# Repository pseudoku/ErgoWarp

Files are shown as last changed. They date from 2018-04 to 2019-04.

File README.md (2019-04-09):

# ErgoWarp
Design Log and Code Repo for ''''Customizable'''' Split Keyboard

# **Still under construction, expect a lot of idiotic word salad and grammatical errors**
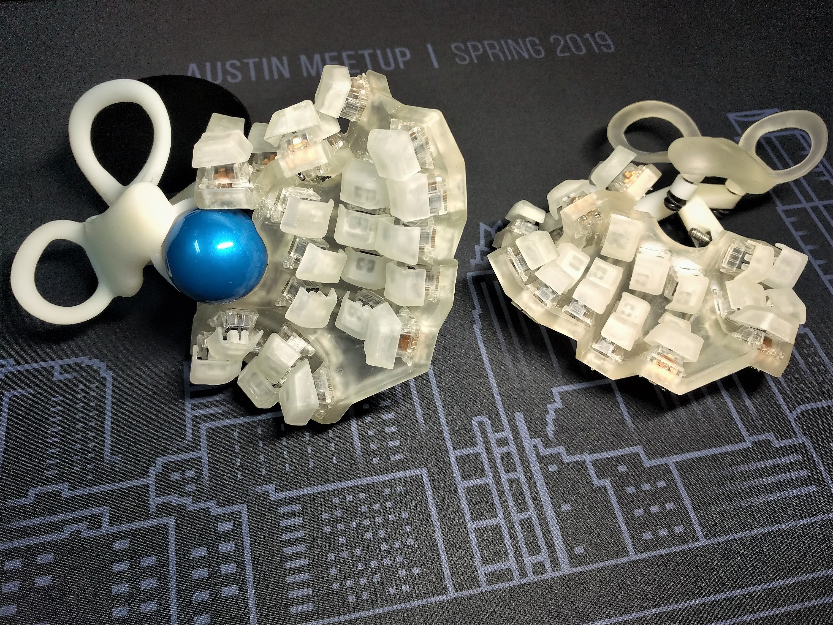
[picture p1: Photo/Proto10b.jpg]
Prototype Rev 10


## Index
 * Introduction
 * Design Goals
 * Design Justifications
  * Row Placement
  * Column Placement
  * Compact Switches
  * Thumb Cluster Design
  * Palm Rest Design
  * Tracking Device Design
 * Observation
 * Alternate Layout

## Introduction

Thanks to this ever-growing and enthusiastic community, there are several options for [split scooped keyboard designs](https://github.com/BenRoe/awesome-mechanical-keyboard) and if you are willing to put some effort into printing and building a pair, you can have your very own as well. However, once I began to play around with them, they raised more questions than what they seemed fix: typing experience of thumb cluster and pinkie columns improved, but still felt awkward at times, necessity to still move my wrist in order to access inner index columns, why not account the key orientations and contour radius to actual fingers motion? etc. etc. I could no longer justify why I need to suffer physically by design concepts of kind and knowledgeable, yet intangible netizen smug with their take on this modern torturing device. I want in on smugness quotas, too. So began my financial woe and mental suffering... And here you are, dredging up this repo page somehow and before your waning attention span exhaust, I will attempt to describe my concepts and experiences of this process in details you have never asked for.

Glory to Datahand and Tron, our ergo forefathers.

## Design Goals:
* Customizable parametric key placement
* Minimize finger movement
* Dense and comfortable thumb cluster
* Built-in ~~adjustable~~ palm rest
* Adjustable tenting
* Tracking device

## Design Justifications

### Row Placement
**Mapping finger flexion to a placement function:**
 To achieve a minimum finger movement, more aggressive row wise contour is desirable. Let us define two arcs of a finger tip during a flexion: inner (distal and intermediate flexion) and outer(distal, intermediate, proximal flexion) with palm side of metacarpal phalangeal joint as the origin. These arcs are mapped to a parametric functions defining the radius of an arc at a given angle from origin with 0° as neutral full extension and 90° as full flexion. They simulate trigger motion and grab motion respectively and it is assumed that optimal row placements of keys reside somewhere between two such functions.

 Please put Finger Path image here

 Using a CAD program I devised following ad hoc rules that will accommodate switches in the arcs.

* Define R0 as a natural trigger, orientated tangential to the inner arc at θ= ~90° to simulate full flexion. Switch origin is offset to the top of mx switch housing.
* Define R2 as a natural tap, orientated normal to the outer arc at θ= ~60°. Switch origin is bottom of the mx switch housing.
* Define R1 as a neutral position that reside between above mentioned positions based on the following rules. Switch origin is bottom of the mx switch housing.
  * Define secondary origin, an intermediate joint of a finger at natural full extension θ= 0°
  * An angle bisected by vectors pointing to the secondary origin R0 and R2 position.
  * Intersection of bisected vector and the outer path and key orientated normal to the path.
* Define R3 as a mirrored of R1 vector across R2. Switch origin is bottom of the mx switch housing.

#### Additional parameters

**path radius offset:** for shorter fingers (ring and pinkie for me), switches origin must be offset to accommodate the switch and keycaps to avoid collision.  

**roll angle:** When I fold my fingers, fingertip does not stay parallel nor in-plane with respect to vector spanned by proximal phalanx and metacarpal. This deviation becomes noticeable with high contour column and column origin transformation does not correct it.(such as adding yaw: see below section). Therefore, roll transformation was added to reorient switches out of columnar plane to bring key orientation closer to natural path of finger tips.

### Column Design
Each origins of columns defined above can be transformed to fit the natural spread and orientation of fingers. For better (ergonomically) or worse (design complexity), We can loosen the orthogonality restriction between columns and gain the freedom to yaw and roll the columns to conform to the arch of palm. With the traditional mx switch and keycap, the out of plane features collide with adjacent columns when optimized for correct placement. Without desperate measures, as we will discuss later, the compromised placement with a high contour leads to a typing experience that was subpar at best, given my finger length and spread. Major issue was that the outer most keys such as outer index and pinkie top rows required wrist motion and exaggerated extensions to hit the keys. This may not be the case for those with longer fingers and requires inputs from those who is willing to try this design.

Notes on some of the observations made during the design iteration on each columns without applying compact switches.
* Column 0: (Ternary Index) though feasible, difficult to press and infrequently used key set recommended (see Prototype 1) R0 is somewhat accessible, if you must.
* Column 1: (Secondary Index) Rolled by 20°, at this angle R0 caps (DSA) corner must be shaved.
* Column 2: (Primary Index)  not rolled, though ideally 15° is desirable, but it would collide with C3. There is also natural yaw of ~12°, but in order to accommodate C0 & C1 it is ignored.
* Column 3: (Middle) 9° roll. ideally more is desirable.   
* Column 4: (Ring) 12° switch roll. ~10° yaw is desirable.  
* Column 5: (Pinky) neutral position has great enough yaw ~42° to split the column from the rest, as observed in top view.
 column without aggressive yaw was tested, but the result required continual effort to keep finger on columns.
* Column 6: (Secondary Pinky) R0 and R1 is good candidate. It's an attractive option if you wish to support such tradition rather than using the thumb cluster.  

### Compact Switches
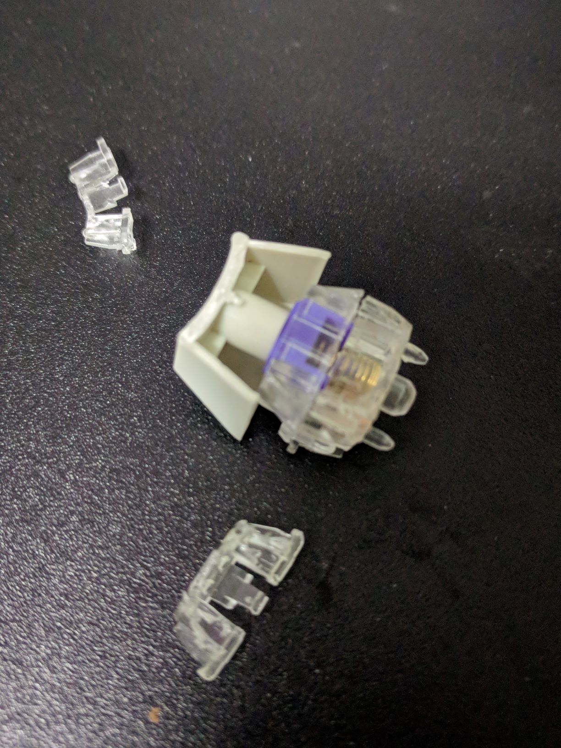
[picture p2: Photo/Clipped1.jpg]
Poor man's compact switches

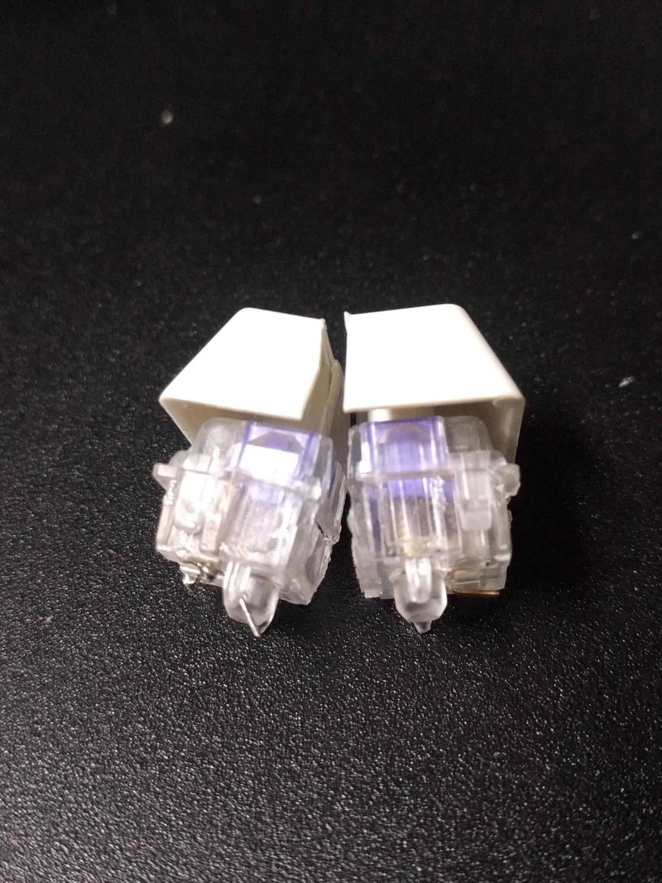
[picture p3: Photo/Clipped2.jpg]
That's a lot of damage

My initial intention of this project was to keep the design accessible by limiting to commercially available switches and keycaps, I did not wish to invest time redesigning key profiles; however, what was available no longer sufficed to the requirement: narrower design something along the line of [alps SKCM compact](https://www.desthority.com) was needed. These are *not readily available* in large quantities and keycaps more so. As a desperation, I resorted to lopping off the LED compartment of MX switches as well as few keycaps to test the feasibility of such. The result was not pleasing to say the least, but it allowed optimization. Not entirely enthralled, but few test prints proved that the pro out weighed the cons:

#### cons:
* produced large wobble that hinders off axis press without gluing casing together
* switch will no longer seat flush to the plate and will tilt without additional support (PCB or glue)
* normal clipped keycap profile are no longer viable and custom profile will be required to improve typing comfort.

#### pros:
* by clipping switch column wise, column separation can be reduced
  * especially useful for outer columns, which reduce wrist motions and extension required.
* allows more aggressive row contour when necessary.
  * by clipping switch row wise, extension need to actuate adjacent upper row can be reduced: pinkie home row (C5R1)
  * by clipping switch row wise, reduce off axis press for num: ring and middle num row (C3&4R3s)
* allows more aggressive column rolling and yaw
  * more natural ring and pinkie column orientation
* allows thumb cluster optimization (discussed next section)

Custom key caps brought some benefits as well:
* inclined tilt for upper row improves actuation motion    
* convex curvature for R0 to reduce discomfort  

Notes on column with compact switches.
* **Column 0: (Ternary Index)
* Column 1: (Secondary Index)
* Column 2: (Primary Index)  not rolled, though ideally 15° is desirable, but it would collide with C3. There is also natural yaw of ~12°, but in order to accommodate C0 & C1 it is ignored.
* Column 3: (Middle) 9° roll. ideally more is desirable.   
* Column 4: (Ring) 12° switch roll. ~10° yaw is desirable.  
* Column 5: (Pinky) neutral position has great enough yaw ~42° to split the column from the rest, as observed in top view.
 column without aggressive yaw was tested, but the result required continual effort to keep finger on columns.
* Column 6: (Secondary Pinky) R0 and R1 is good candidate. It's an attractive option if you wish to support such tradition rather than using the thumb cluster.**  

### Thumb Cluster Design
I have created stick representation of my thumb in OpenSCAD and initial attempts sought to pack as many switches near the ideal thumb motion without considering collision. While keys were accessible they did not produce efficient press and produced strain because thumb position. I've replicated and tested other notable design philosophy: datahard, manuform, and dmote to ended up with following design criteria ordered in priority:

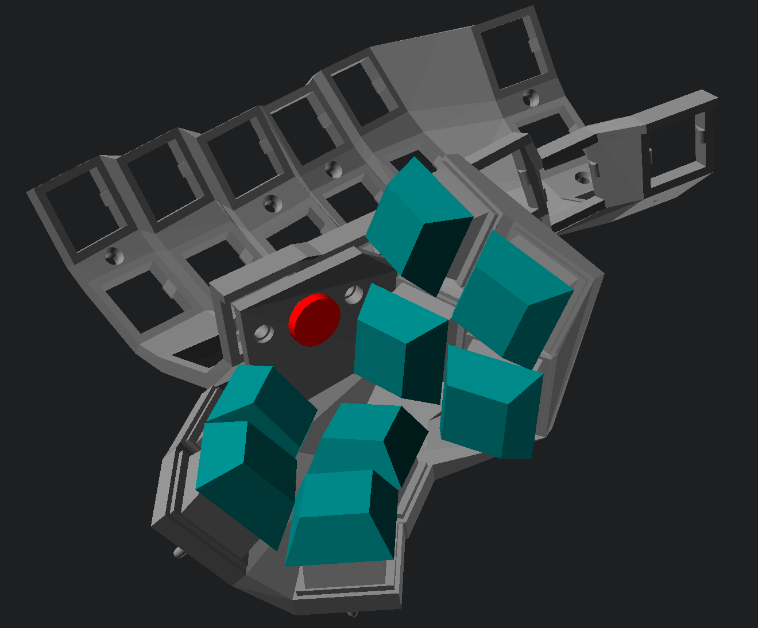
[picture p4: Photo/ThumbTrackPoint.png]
Initial Design


* **Place highest priority on thumb home. cluster must be as close to thumb neutral position and orientation**

 Compromising this is the cardinal sin of design and it is exacerbated when number of clutter keys density increases. To accomplish this for ErgoWarp, C1R0 (secondary index bottom row) was removed and replaced with C0R1 (ternary index home row) which allowed thumb cluster to come closer to its optimal location.

 _Natural thumb position should be measured with ones hand down by one's side not at the typing position (arm out); thumb abduction will be exaggerated leading to incorrect optimization_
* **Prefer actuation with palm sides surface (adduction and flexion and not abduction and extension)**

  ~~Most compact split keyboards rely on 1u thumb clusters, with it We are accustomed to pressing space bar with side of the thumb, so much so that I was recreating this bad design despite given the opportunity to correct them. All three mentioned forerunners have broken out of the box albite with their choice of priorities and compromises. When press orientation becomes thumb flexion near the neutral thumb position, the use of heavy switch must be avoided, as the torque will shift wrist position which creates strain when chording with same hand fingers. DataHand breaks this design philosophy, but it is the result of adapting light low travel switch irreplicable with mx switches. manuform follows this to the t, but by reducing the priority to minimize motion. dmote also follows this, but prioritize cluster density over correct orientations.~~ needs edit

* **Minimize travel distance while maintaining correct press orientation**

  This also means that high concave contour designs that conforms to the key profiles should be avoided. To reiterate, avoid adapting datahand like welled cluster with mx switches; they may reduce travel somewhat, but it is in no way a comfortable design nor do they allow accurate chording. The design goal seems conflicting statement with normal mx switches, but by uti
* **Ability to chord press**

  It is desirable to place modifiers and layers on thumb cluster, but without the ability to chord them effectively, their utility is hampered. especially when this design takes away conventional bottom row modifiers. Utilizing super, hyper modifiers, layers and tap modifiers are well intended, but compromised solution adding mental load when good thumb cluster design can do it all. Avoiding awkward wrist position and motion when chording requires all mentioned design goals.

result is a compact six key design akin to dmote. justification and description of each position below:

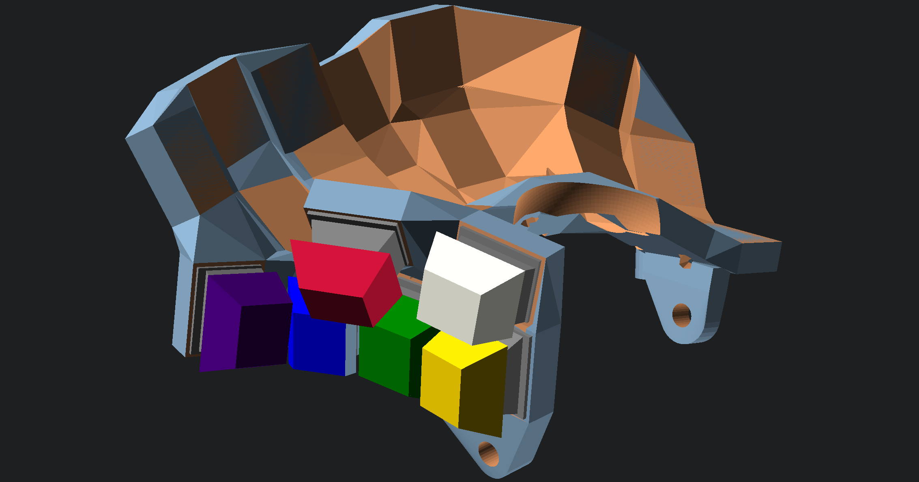
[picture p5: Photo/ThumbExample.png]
Thumb Cluster

first three are neutral position cluster requiring minimum movement to actuate.
T0(red): actuated by a neutral tip addution, simulating a pinching motion. it is the most comfortable press and since its motion separate, least prone to miss-press. thus it is the home key.
T1(blue):  neutral tip. this can be actuated by combing distal flexion. allows fast transition from homekey and is best suited for layer or shift.
T2(green):  placement-wise this is closest to the true neutral position of thumb by flexing medial joint the switch can be actuated, or by sliding. also efficient allows chording between T3 and T4.  

the next three are outer sets that
T3(white): adduction with flexed distal faster of outer set.
T4(purple):
T5(yellow)

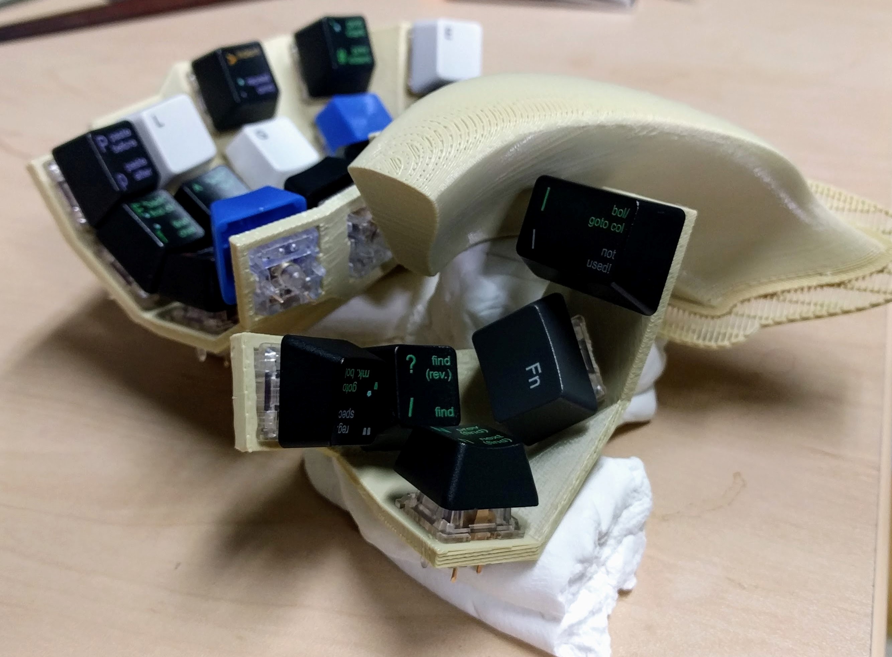
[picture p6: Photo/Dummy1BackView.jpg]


cylinder represents the thumb. (thumb cluster ver2)

Thumb cluster desirable traits:

dox like style attempt to minimize travel by having normal cluster and maintain chording to a degree, but often the thumb home is too. but
  problem with side adduction press is that it produce strenuous press when combine with high extension.

manuform break the compact cluster criteria to achieve correct orientation. but by doing so with normal switches produce longer travel distance and loose efficiency on outer keys.

datahard I have not tried, but cluster similar to such layout did not pass. mainly due to mx switches fails due to its longer actuation throws.
similarly high concave contour was not good enough

dmote overall cluster press orientation is mostly correct, but chording is not ideal, home is too far from neutral(with my thumb length) and high collision with index columns. Clustering seems to be prioritize over orientation for anterior presses and seems awkward.   

with compact mx switches
 1. narrower index columns improves thumb home position and reduces collision issue
 2. further improve thumb home position by getting moving of bottom row on secondary index to home row ternary index     
 3. decouple orientation and distance,
    a) minimize adjacent switch distance with out resorting to high contour
    b) correct orientation without lower collision issues

## Palm Rest Design
~~wrist rest~~
~~putting load on nerve path of hand and palm all cost and distribute the load properly.
a supporting structure that conforms to the cavity created by the natural arch of the palm.  
they are modeled by a sweep of traversing center with a ellipsoid  
a supporting structure that conforms to the cavity created by the natural arch of the palm.  
they are modeled by a sweep of traversing center with a ellipsoid. palm support alone is insufficient in my opinion as they do not distribute weight enough and not enough constraints as the hand moves and slips out of the support. an additional support were required.~~

a distorted ring that supports thumb metacarpal and it's ellipsoidal blob, but avoid index/thumb nerve channel.

a distorted ring that support pinkie metacarpal and it's ellipsoidal blob
when angle of tenting becomes sufficiently high >30 a proper support is required at edge side of the palm to discourage slippage while allowing free movement of pinkie finger.

## Tracking Device -*Incomplete*-
###Trackpoint
Prototype 1, 4, and 5 were made with Trackpoint in mind, but due severe drifting issue I could not completed usage test. After some input from another forerunner, to The cause of the drift was most likely due to me roughing around the module housing and poor mounting which applied constant distortion on module. TODO Repeat test

####Trackpoint with Switch integration

An adapter for MX key stubs to trackpoint stub. compounding with navigation layer was attractive. Tried with prototypes 4 and 5. produced mushy feel and noise.

###Trackball: under construction

## Alternate Layout: Warpman
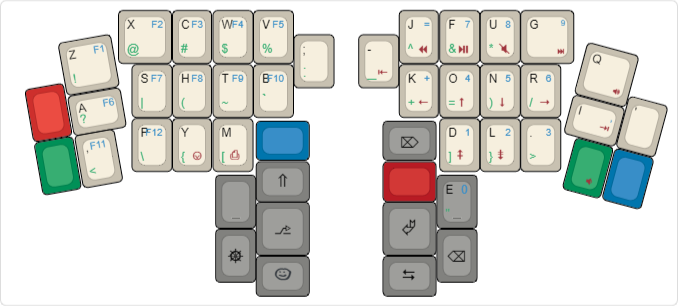
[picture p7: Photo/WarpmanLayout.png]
Layout warpman


The effort map changed considerably to a point that I felt it was a valid excuse to consider my own layout. Vertical downward transitions are faster and Workman layout philosophy jived well on initial trial. With the reduced effort to actuate bottom row, allocating higher frequency letters was less of an issue. Generous thumb cluster also made sense to adopt maltron like thumb layout. As a personal preference, emphasis on rolling and same hand typing were also considered.

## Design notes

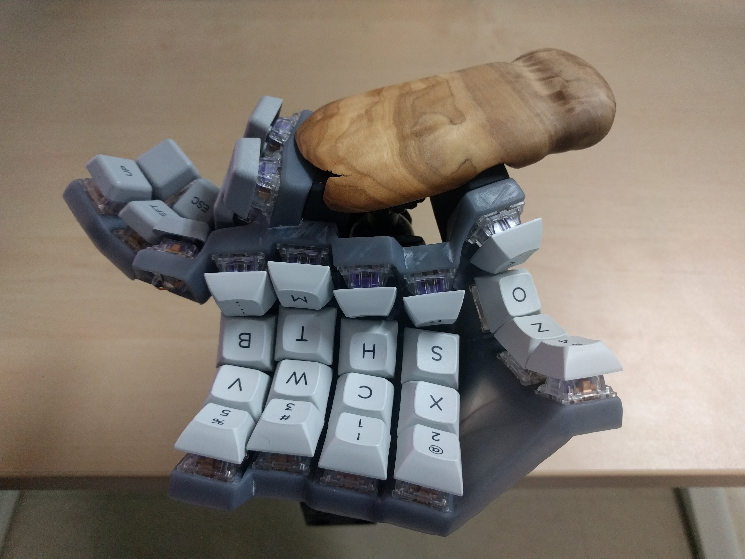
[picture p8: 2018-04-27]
Photo/Proto2FrontView.jpg

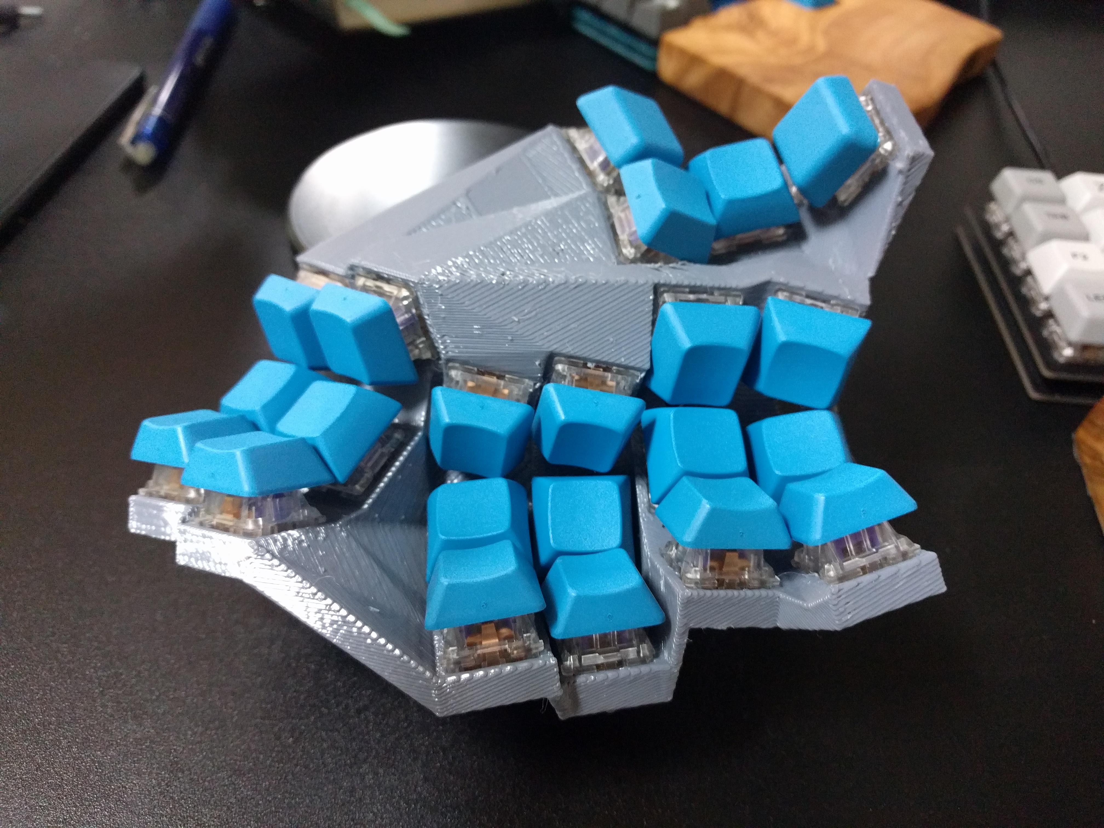
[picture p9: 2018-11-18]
Photo/Proto7.jpg

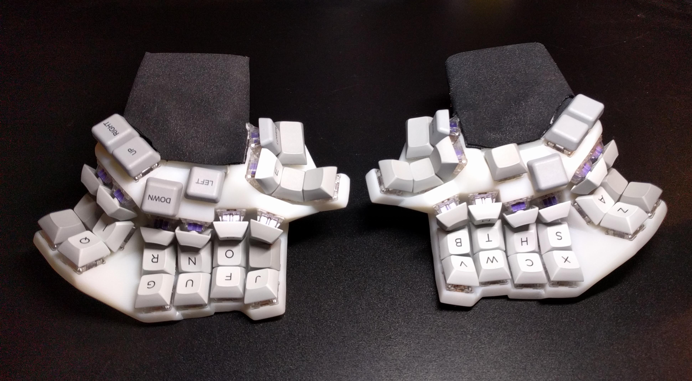
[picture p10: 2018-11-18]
Photo/Proto6.jpg

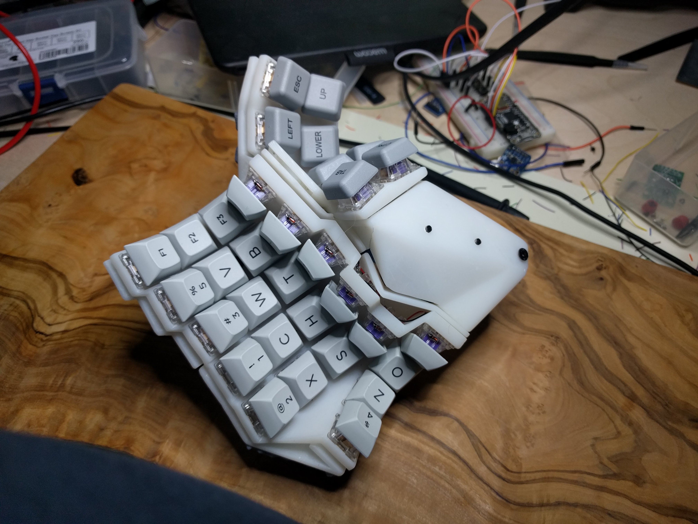
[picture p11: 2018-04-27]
Photo/Proto1FrontView.jpg

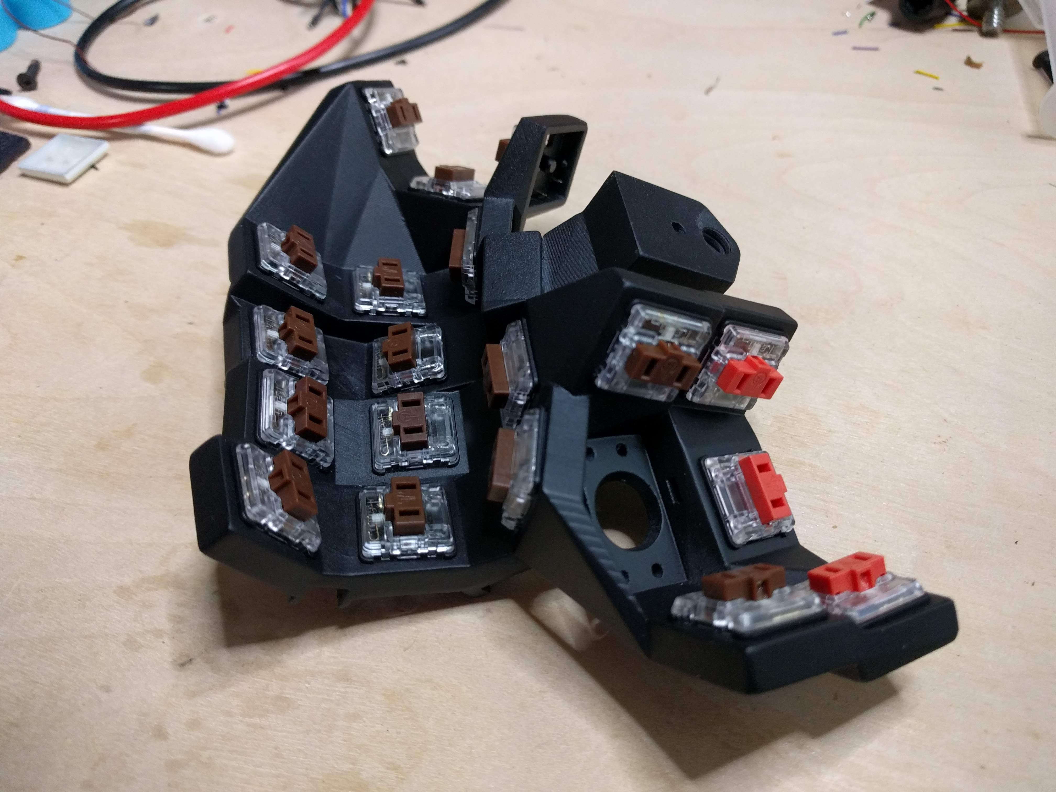
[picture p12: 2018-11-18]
Photo/Proto5.jpg

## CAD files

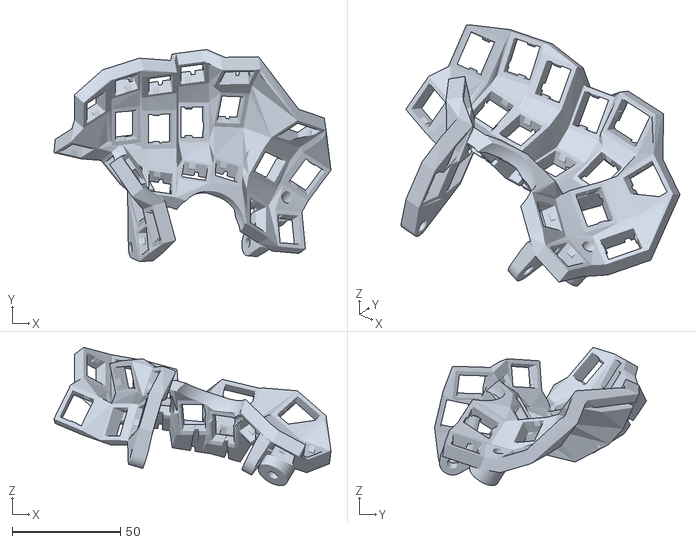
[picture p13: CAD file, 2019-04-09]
Things/STL/HyperWarpWithTrackBall.stl
128.1 x 98.0 x 64.0

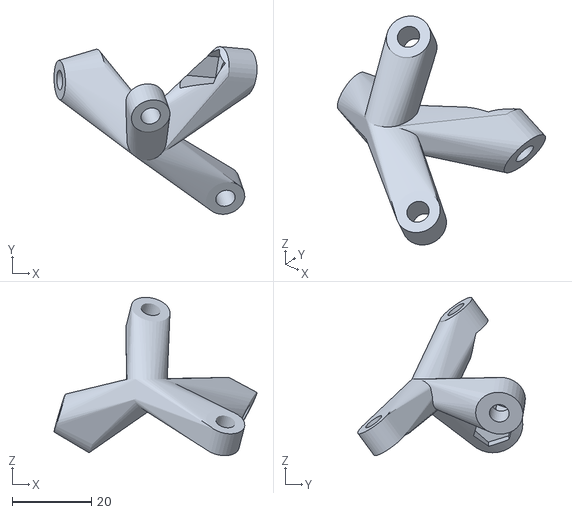
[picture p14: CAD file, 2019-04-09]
Things/STL/PalmMount.stl
51.4 x 42.4 x 40.1

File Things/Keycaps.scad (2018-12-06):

/* [Key] */
use <scad-utils/morphology.scad> //for cheaper minwoski 

key_length = 1;  //length in units of key
key_height = 1;  //height in units of key. should remain 1 for most uses

keytop_thickness = 2;  // keytop thickness, aka how many millimeters between the inside and outside of the top surface of the key
wall_thickness = 3;    // wall thickness, aka the thickness of the sides of the keycap. note: 3 = 1.5mm walls

/* [Brim] */
has_brim = 0;//enable brim for connector
brim_radius = 11; //brim radius. 11 ensconces normal keycap stem in normal keycap
brim_depth = .3;  //brim depth

/* [Dish] */
 // invert dishing. mostly for spacebar

/* [Stem] */
stem_profile = 0;  // cherry MX or Alps stem, or totally broken circular cherry stem [0..2]
stem_inset = 0;    // how inset the stem is from the bottom of the k ey. experimental. requires support
stem_offset = 0;   // stem offset in units NOT MM. for stepped caps lock

/* [Hidden] */
$fn = 32;          //change to round things better
resfactor = 8;   //fn division factor to reduce load
unit = 19.05;      //beginning to use unit instead of baked in 19.05
minkowski_radius = 1.75; //minkowski radius. radius of sphere used in minkowski sum for minkowski_key function. 1.75 default for faux G20

//profile specific stuff

/*
 1.  Bottom Key Width: width of the immediate bottom of the key
 2.  Bottom Key Height: height of the immediate bottom of the key
 3.  Top Key Width Difference: mm to subtract from bottom key width to create top key width
 4.  Top Key Height Difference: mm to subtract from bottom key height to create top key height
 5.  Total Depth: how tall the total in the switch is before dishing
 6.  Top Tilt: X rotation of the top. Top and dish obj are rotated
 7.  Top Skew: Y skew of the top of the key relative to the bottom. DCS has some, DSA has none (its centered)
 8.  Dish Type: type of dishing. check out dish function for the options
 9.  Dish Depth: how many mm to cut into the key with
 10. Dish Radius: radius of dish obj, the Sphere or Cylinder that cuts into the keycap
 11. Dish Inversion 
*/

key_profiles = [
// BotWid     BotLen  TopWidD TopLenD totDep  TopTilt TopSkew | DishType DishDep  DishSkewX DishSkewY DishInv
  [18.16,     18.16,  2, 	    2,      6,	    2.5,    0.75,     3,       0,       0,        0,        false],//C0R0 clipped G20 like 
	[18.16,     18.16,  6,      4,      8.5,    -1,     1.75,     0,       1,       0,        0,        false],//C0R1 unusede 
	[18.16,     18.16,  6.2,    4,      7.5,	  3,      1.75,     0,       1,       0,        0,        false],//C0R2 unused 
  
	[18.16,     18.16,  5.7,    4,      7.4,    -2,     -1.5,     1,       1.2,     0,        0,        false],//C1R0 clipped G20 like
	[18.16,     18.16,  5.7,    5.7,    7.4,    0,      0,        1,       1.2,     0,        0,        false],//C1R1 clipped G20 DSA 
  [18.16,     18.16,  5.7,    4,      7.4,    -5,      1.5,     1,       1.2,     0,        0,        false],//C1R2 clipped G20 like
  
	[18.4,      18.4,   3,      5.7,    7.4,    0,      0,        1,       2,       -3,        -2,        false],//C2R0 clipped tilted
	[18.4,      18.4,   3,      5.7,    7.4,    0,      0,        1,       2,       -3,        0,        false],//C2R1 clipped tilted
	[18.4,      18.4,   3,      5.7,    7.4,    -5,     1.5,      1,       2,       -3,        0,        false],//C2R2 clipped tilted
  
	[18.4,      18.4,   5.7,    5.7,    7.4,    -5,      -1,       1,      1.2,     0,        0,       false],//C3R0
	[18.4,      18.4,   5.7,    5.7,    7.4,    0,      0,        1,       1.2,     0,        0,        false],//C3R1 Norm DSA
	[18.16,     18.16,  5.7,    4,      7.5,    -5,     1.5,      0,       1,       0,        0,        false],//C3R2
  
  [18.4,      18.4,   5.7,    5.7,    7.4,    -5,      0,        1,       1.2,     0,        0,        false],//C4R0
	[18.4,      18.4,   5.7,    5.7,    7.4,    0,      0,        1,       1.2,     0,        0,        false],//C4R1
	[18.16,     18.16,  5.7,    3,      7.5,	  -5,     1.5,      0,       1,       0,        0,        false],//C4R2
  
	[18.16,     18.16,  5.7,    4,      6.2,    7,      1.75,     0,       1,       0,        0,        false],//C5R0
	[18.4,      18.4,   5.7,    5.7,    7.4,    0,      0,        1,       1.2,     0,        0,        false],//C5R1
  [18.16,     18.16,  5.7,    3,      7.5,	   -5,     1.5,      0,       1,       0,        0,        false],//C5R2
  
	[18.16,     18.16,  4,      6,      7.4,      6,     -1.5,      1,     1.2,     0,        0,       false],//C6R0
	[18.16,     18.16,  4,      5.7,    7.4,      0,      0,        1,     .5,      0,        0,       false],//C6R1  true
	[18.16,     18.16,  4,      3,      7.5,	   -4,      1.5,      1,     1,       1,        -1,        false] //C6R2 
];
test = 20;
mirror([1,0,0])keycap(test, clipOrientation = false, clipLen = -4);
/*
references
// BotWid     BotLen  TopWidD TopLenD totDep  TopTilt TopSkew | DishType DishDep  DishSkewX DishSkewY
  [18.16,     18.16,  6,      4,      11.5,   -6,     1.75,     0,       1,       0,        0],//DCS ROW 5
	[18.16,     18.16,  6,      4,      8.5,    -1,     1.75,     0,       1,       0,        0],//DCS ROW 1
	[18.16,     18.16,  6.2,    4,      7.5,	  3,      1.75,     0,       1,       0,        0],//DCS ROW 2
	[18.16,     18.16,  6,      4,      6.2,    7,      1.75,     0,       1,       0,        0],//DCS ROW 3
	[18.16,     18.16,  6,      4,      6.2,	  16,     1.75,     0,       1,       0,        0],//DCS ROW 4
	[18.4,      18.4,   5.7,    5.7,    7.4,    0,      0,        1,       1.2,     0,        0],//DSA ROW 3
	[18.4,      18.4,   5.7,    5.7,    13.73,  0,      -14,      1,       1.2,     0,        0],//SA ROW 1
	[18.4,      18.4,   5.7,    5.7,    11.73,  -7,     0,        1,       1.2,     0,        0],//SA ROW 2
	[18.4,      18.4,   5.7,    5.7,    11.73,  0,      0,        1,       1.2,     0,        0],//SA ROW 3
	[18.4,      18.4,   5.7,    5.7,    11.73,  7,      0,        1,       1.2,     0,        0],//SA ROW 4
	[18.16,     18.16,  6,      4,      6.2,    16,     1.75,     2,       1,       0,        0],//DCS ROW 4 SPACEBAR
	[18.16,     18.16,  2, 	    2,      6,	    2.5,    0.75,     3,       0,       0,        0],//G20 AKA DCS Row 2 with no dish
*/

function capDim(capIDs, dimIDs) = key_profiles[capIDs][dimIDs];
echo(capDim(5, bottom_key_width));
// Alias for dimID 
bottom_key_width = 0;
bottom_key_height = 1;
width_difference = 2;
height_difference = 3;
total_depth = 4;
top_tilt = 5;  // assume key_height remains 1
top_skew = 6;
dish_type = 7;
dish_depth = 8;
dish_skew_x = 9;
dish_skew_y = 10;
inverted_dish = 11;
// actual mm key width and height
function total_key_width(capIDs) = capDim(capIDs,bottom_key_width) + (unit * (key_length - 1));
function total_key_height(capIDs) = capDim(capIDs,bottom_key_height) + (unit * (key_height - 1));

// actual mm key width and height at the top
function top_total_key_width(capIDs) = capDim(capIDs,bottom_key_width) + (unit * (key_length - 1)) - capDim(capIDs,width_difference);
function top_total_key_height(capIDs) = capDim(capIDs,bottom_key_height) + (unit * (key_height - 1)) - capDim(capIDs,height_difference);


module roundedRect(size = [0,0,0], radius= 1.5) { //simplified to single call using Morphology Util lib
  linear_extrude(size[2])rounding(r=radius)square([size[0], size[1]], center = true);
}

//------  stem related stuff
module inside(){
	difference(){
		translate([0,0,50]) cube([100000,100000,100000],center=true);
		shape(0, 0);
	}
}

module cherry_stem(){
  cross_length = 4.4;                 // cross length
  extra_vertical_cross_length = 1.1;  //extra vertical cross length - the extra length of the up/down bar of the cross
	extra_outer_cross_width = 2.10;   	// outer cross extra length in x
	extra_outer_cross_height = 1.0;     // outer cross extra length in y
	horizontal_cross_width = 1.4;       // horizontal cross bar width
	vertical_cross_width = 1.3;  	      // vertical cross bar width
	cross_depth = 4;   	                // cross depth, stem height is 3.4mm

	difference(){
    union(){
      if (stem_profile != 2){
        translate([0,0,7.5])
    			rotate([0,0,90])cube([cross_length+extra_outer_cross_width, cross_length+extra_outer_cross_height, 15], center = true);
      }
      else {
        cylinder(d = cross_length+extra_outer_cross_height, h = 15);
      }
			if (has_brim == 1){ cylinder(r=brim_radius,h=brim_depth); }
		}
		//the cross part of the steam
		translate([0,0,(cross_depth)/2 + stem_inset])rotate([0,0,90]){
	        cube([vertical_cross_width,cross_length+extra_vertical_cross_length,cross_depth], center=true );
	        cube([cross_length,horizontal_cross_width,cross_depth], center=true );
	  }
	}
}

module alps_stem(){
	cross_depth = 40;
	width = 4.45;
	height = 2.25;
	base_width = 12;
	base_height = 15;

	translate([0,0,cross_depth/2 + stem_inset])cube([width,height,cross_depth], center = true);
}
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

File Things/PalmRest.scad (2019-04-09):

//Palm rest 
use <sweep.scad>
use <scad-utils/transformations.scad>
use <scad-utils/morphology.scad> //for cheaper minwoski 
use <scad-utils/lists.scad>
use <scad-utils/shapes.scad>
use <scad-utils/trajectory.scad>
use <scad-utils/trajectory_path.scad>
use <skin.scad>  

//--- parametrization of hand model
$fn = 48;
step = 5;
dMount = 5.1054; // mounting bore size
dMountMM = 5;
dBall    = 18; //for ball mount  

len_ind   = 68; 
len_mid   = 88; //from mid knuckle to base of wrist 
wid_pin   = 23;
len_wrist = len_mid + 12; // from mid knuckle to base of wrist band
len_thumb = len_mid - 0;
hei_thumb = 4;

ang_pin   = [5,10,10];
ang_ring  = [0,12,20];
ang_thumb = [-15,-65,0];
ang_ind   = [70,-75,0];

//--- shorthard transform to blob center
module origin_pinkie() {translate([wid_pin,0,-len_mid])rotate(ang_pin)rotate([0,90,30])translate([-16,5,-10])children();}
module origin_ring() {
  translate([wid_pin,0,-len_mid])rotate(ang_ring)translate([0,30,33])rotate(ang_ind)translate([10,30,12])children();
  }
module origin_thumb() {translate([0,hei_thumb,-len_thumb])rotate(ang_thumb)translate([0,-6,35])children();}
module origin_palm(){translate([wid_pin,0,-len_mid])rotate(ang_pin)children();}

//Path function. 
  function oval_path(theta, phi, a, b, c, deform = 0) = [
   a*cos(theta)*cos(phi), //x
   c*sin(theta)*(1+deform*cos(theta)) , // 
   b*sin(phi),
  ];

  //oval path with linear angle offset 
  function oval_path2(theta, phi_init, a, b, c, d = 0, p = 1, deform = 0) = [
   a*cos(theta)*cos(phi_init), //x
   b*sin(theta)*(1+deform*cos(theta))*cos(phi_init + d * sin(theta*p)), // 
   c*sin(phi_init + d * sin(theta*p))
  ];

  //oval path with angle offset with hypersine 
  function oval_path3(theta, phi_init, a, b, c, d = 0, p = 1, deform = 0) = [
   a*cos(theta)*cos(phi_init), //x
   b*sin(theta)*(1+deform*cos(theta))*cos(phi_init + d * pow(sin(theta*p), 1)), // 
   c*sin(phi_init + d * pow(sin(theta*p), 3))
  ];

//shape functions 
function ellipse(a, b, d = 0) = [for (t = [0:step:360]) [a*cos(t), b*sin(t)*(1+d*cos(t))]]; //shape to 
function ellipse2(a1, b1, a2, b2, d1 = 0, d2 = 0 ) = [for (t = [0:step:360]) t>180 ? [a1*cos(t), b1*sin(t)*(1+d1*cos(t))] : [a2*cos(t), b2*sin(t)*(1+d2*cos(t))] ]; //shape to 
  
function ellipse3(a1, b1, a2, b2, d1 = 0, d2 = 0 ) = [for (t = [0:step:360]) (t>90 && t<270) ? [a1*cos(t), b1*sin(t)*(1+d1*cos(t))] : [a2*cos(t), b2*sin(t)*(1+d2*cos(t))] ]; //shape to 
  
// sweep generators 
// pinkie palm ring 
module pinkie_ring() {
  a = 26;
  b = 18; 
  c = 15;
  function shape() = ellipse(1.5, 4);
  function shape2() = // ellipse(1.5, 10);
    ellipse3(
    a1 = 1.5,
    b1 = 4,
    a2 = 3, 
    b2 = 4, 
    d1 = 0, 
    d2 = 0);
  
  path_transforms =  [for (t=[0:step:180])   translation(oval_path3(t,40,a,b,c,0,1,-0.1))*rotation([90,-90+10*sin(t/2),t])];
  path_transforms2 = [for (t=[180:step:270]) translation(oval_path3(t,40,a,b,c,15,1,-.1))*rotation([90,-80-30*sin(t),t])];  
  path_transforms3 = [for (t=[270:step:360]) translation(oval_path3(t,40,a,b,c,15,1,-.1))*rotation([90,-90-40*sin(t),t])];  
      
  origin_pinkie()sweep(shape2(), path_transforms);
  origin_pinkie()sweep(shape2(), path_transforms2);
  origin_pinkie()sweep(shape2(), path_transforms3);
}

module thumb_ring() {
  function shape()  = ellipse(4, 2);
  function shape2() = // ellipse(1.5, 10);
    ellipse2(
    a1 = 4,
    b1 = 3,
    a2 = 4, 
    b2 = 2, 
    d1 = 0, 
    d2 = 0);

//  path_transforms =   [for (t=[0:step:185]) translation(oval_path2(t,0,21,10,24,0,1,0))*rotation([90,20*sin(t),t])]; 
  path_transforms  =  [for (t=[  0:step:180]) translation(oval_path3(t,-40,26,22,24,30,1,-0))*rotation([90,0-50*sin(t),t])]; 
  path_transforms2 =  [for (t=[180:step:360]) translation(oval_path2(t,-40,26,21,24,0,1,.2))*rotation([90,20*sin(t),t])];  
  path_transforms3 =  [for (t=[  0:step:180]) translation(oval_path3(t,-40,26,28.5,24,45,1,.2))*rotation([90,0-50*sin(t),t])];  
  
//  origin_thumb()rotate([110,90,0])translate([0,42,0])rotate([90,0,180])sweep(shape2(), path_transforms);
  origin_thumb()rotate([80,90,0])sweep(shape(), path_transforms);// lipped
  origin_thumb()rotate([80,90,0])sweep(shape2(), path_transforms2);// front 
  origin_thumb()rotate([80,90,0])sweep(shape2(), path_transforms3);// Support

}

module palm_track() {
  a = 20;
  b = 20; 
  c = 20;
  //Ellipsoid([20*2,25*2,60],[30*2,25*2,60], center = true);
  function shape() = ellipse(4, 4);
  path_transforms =  [for (t=[0:step:180]) translation(oval_path3(t,20,a,c,b,30,1,0))*rotation([90,-20-20*sin(t),t])]; 
  path_transforms2 =  [for (t=[0:step:180]) translation(oval_path3(t,70,b,a,c,-10,1,0))*rotation([90,-70+5*sin(t),t])];  
//  path_transforms3 =  [for (t=[0:step:360]) translation(oval_path3(t,-5,a,c,b,-15,1,0))*rotation([90,20+15*cos(t),t])];   
  path_transforms3 =  [for (t=[0:step:180]) translation(oval_path3(t,-20,a,c,b,-30,1,0))*rotation([90,20+20*sin(t),t])];   
  path_transforms4 =  [for (t=[0:step:360]) translation(oval_path3(t,10,a,c,b,0,1,0))*rotation([90,-20+sin(t),t])];   
  rotate([-90,0,0])sweep(shape(), path_transforms);
  rotate([90,0,-90])sweep(shape(), path_transforms2);
  rotate([90,0,90])sweep(shape(), path_transforms2);
  rotate([-90,0,0])sweep(shape(), path_transforms3); 
//  rotate([0,0,0])sweep(shape(), path_transforms4); 
}

module pinkie_joint() {
  function shape() = ellipse(1.5, 4);
  path_transforms =  [for (t=[70:step:145])   translation(oval_path3(t,40,28,18,15,0,1,-0.1))*rotation([90,-90+25*sin(t/2),t])];  
      
  origin_pinkie()sweep(shape(), path_transforms);
} 

// Palm Section
steps  = 100; 
Length = 90;
radius = 64; 
theta  = 61; 
theta0 = 20;
function arcPath(dist) =  0.11858892889724*dist+-0.00950842013031634*pow(dist,2)+0.00050907432957908*pow(dist,3)+-3.04498262564168E-06*pow(dist,4)+-6.98665888934242E-08*pow(dist,5)+6.31588918303338E-10*pow(dist,6)+-0.00519577930333526;

function arcScale(dist) = (0.0312718203578395*dist+-0.00324416785860623*pow(dist,2)+0.000178485812677843*pow(dist,3)+-3.73935353737613E-06*pow(dist,4)+3.39032119124653E-08*pow(dist,5)+-1.14731790495239E-10*pow(dist,6)+1.00309198846833)*10;

function arcA(x) = 0.466157140933998*x+-0.0305388845787073*pow(x,2)+0.00217295863467009*pow(x,3)+-6.21175274075925E-05*pow(x,4)+7.44922151927002E-07*pow(x,5)+-3.17841492050627E-09*pow(x,6)+13.8451591429169;

function arcLength(phi) =  radius*(90-phi)/180*PI;

function translateEllipse(x) = [
    radius*sin(x),  //height
    arcPath(arcLength(x)),
    1.3*radius*cos(x) 
];

function scaleEllipse(x) =[
    arcScale(arcLength(x)),
    1,
    1
];

//path2 = [for (t=[19:20]) translation(translateEllipse(t))*rotation([90+t,0,90])*scaling(scaleEllipse(t))];
//path3 = [for (t=[0:theta/steps:theta]) translation(translateEllipse(t))*rotation([90+t,0,90])*scaling(scaleEllipse(t))];
//clip = [for (i=[0:len(path3)-1]) transform(path3[i], ellipse(1, 5, d = .1))];   // skin for main palm structure 
//clip2 = [for (i=[0:len(path2)-1]) transform(path2[i], ellipse(1, 5, d = .1))];  // skin for hulling with pinkie ring

path4 = [for (t=[theta0:theta/steps:theta]) translation(translateEllipse(t))*rotation([90+t,0,90])];
path5 = [for (t=[theta0:theta/steps:theta0+theta/steps]) translation(translateEllipse(t))*rotation([90+t,0,90])];
  
clip3 = [for (i=[0:len(path4)-1]) transform(path4[i], 
  ellipse2(
    a1 = arcA(arcLength(i*theta/steps+theta0)), 
    b1 = 8-6*sin(i*theta/steps),
    a2 = arcA(arcLength(i*theta/steps+theta0)), 
    b2 = 5+4*sin(i*theta/steps), 
    d1 = -.3, 
    d2 = -.4)
)];   // skin for main palm structure 
clip4 = [for (i=[0:len(path5)-1]) transform(path5[i], 
   ellipse2(
    a1 = arcA(arcLength(i*theta/steps+theta0)), 
    b1 = 8-6*sin(i*theta/steps),
    a2 = arcA(arcLength(i*theta/steps+theta0)), 
    b2 = 5+4*sin(i*theta/steps), 
    d1 = -.3, 
    d2 = -.4)
)];   // skin for main palm structure  // skin for main palm structure
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

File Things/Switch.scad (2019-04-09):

plate_thickness = 1;
plate_size = 15.6;
edge_offset = 1;
bottom_height = 5;
bottom_size = plate_size - 2;

top_height = 11.6;

switch_height = 3.0;
switch_thick = 1;
switch_width = 5;
switch_length = 3;

cap_height = .38*25.4;
cap_heightShift = 0.69*25.4;
cap_width = 18.3;

clip_Length = 3;  // length clipped

//dummy key switch with caps to check position
module Switch(switchScale= [1,1,1], colors = "teal", clipLength = 0)
{
  difference(){
    union(){
      translate([0,0,-switch_height])
      {
        color("grey"){
          translate([-bottom_size/2, -bottom_size/2 ,0])cube([bottom_size,bottom_size,bottom_height]);
          translate([-plate_size/2-edge_offset /2, -plate_size/2-edge_offset/2, bottom_height])cube([15.6+edge_offset ,15.6+edge_offset ,1]);

          translate([-plate_size/2, -plate_size/2, bottom_height])cube([15.6,15.6,1]);
          translate([-plate_size/2, -plate_size/2, bottom_height])cube([15.6,15.6,1]);

          translate([0,0, bottom_height+plate_thickness])translate([-15.6/2,13.6/2,0])rotate([90,0,0])linear_extrude(13.6)polygon(points = [[0,0], [15.6, 0], [13.6, 5.6], [2,5.6]]);
        }

        color("purple"){
          translate([-switch_width/2, -switch_thick/2, top_height])cube([switch_width, switch_thick, switch_height]);
          translate([-switch_thick/2, -switch_length/2, top_height])cube([switch_thick, switch_length, switch_height]);
          translate([-plate_size/4, -plate_size/6, top_height])cube([plate_size/2, plate_size/3, 0.25]);
        }

        scale(switchScale)color(colors){
          translate([0,0,cap_heightShift-2])rotate([0,0,45])cylinder(d1 = cap_width*sqrt(2),d2 = (plate_size -4)*sqrt(2), 7.5, $fn=4, center = true);
        }
        bottom_height = 4.5;
        bottom_chamfer_width = 3.05;
        bottom_chamfer_height =  1;
        bottom_chamfer_thickness = .6;

        bottom_peg_diameter = 4.075/.97;
        bottom_peg_height =  3.5;
        bottom_peg_chamfer = .5;
        bottom_peg_side_scale = 1.7/4;

        color("grey"){
          translate([0,0, -(bottom_peg_height -bottom_peg_chamfer)]){
            cylinder(d=bottom_peg_diameter, h= bottom_peg_height -bottom_peg_chamfer);
            translate([5,0,0])scale(v=[bottom_peg_side_scale,bottom_peg_side_scale,1])cylinder(d=bottom_peg_diameter, h= bottom_peg_height -bottom_peg_chamfer);
            translate([-5,0,0])scale(v=[bottom_peg_side_scale,bottom_peg_side_scale,1])cylinder(d=bottom_peg_diameter, h= bottom_peg_height -bottom_peg_chamfer);

            translate([0,0, -bottom_peg_chamfer]){
              cylinder(d2=bottom_peg_diameter , d1 = bottom_peg_diameter -2*bottom_peg_chamfer, h= bottom_peg_chamfer);
              translate([5,0,0])scale(v=[bottom_peg_side_scale,bottom_peg_side_scale,1])cylinder(d2=bottom_peg_diameter , d1 = bottom_peg_diameter -2*bottom_peg_chamfer, h= bottom_peg_chamfer);
              translate([-5,0,0])scale(v=[bottom_peg_side_scale,bottom_peg_side_scale,1])cylinder(d2=bottom_peg_diameter , d1 = bottom_peg_diameter -2*bottom_peg_chamfer, h= bottom_peg_chamfer);
            }
          }
        }
      }
    }
    if (clipLength != 0){ // commiting unholy act in name of ergonomics
      translate([0, -sign(clipLength)*7.8-clipLength,  0])cube([20, 15.6, 40], center = true);
    }
  }
}

module Cutter()
{
  bottom_height = 4.5;
  bottom_chamfer_width = 3;
  bottom_chamfer_height =  1;
  bottom_chamfer_thickness = .6;

  bottom_peg_diameter = 4;
  bottom_peg_height =  3;
  bottom_peg_chamfer = 1;
  bottom_peg_side_scale = 1.7/4;

  translate([-bottom_size/2, -bottom_size/2 ,0])cube([bottom_size,bottom_size,bottom_height]);

  translate([0,0, -(bottom_peg_height -bottom_peg_chamfer)]){
    cylinder(d=bottom_peg_diameter, h= bottom_peg_height -bottom_peg_chamfer);
    translate([5,0,0])scale(v=[bottom_peg_side_scale,bottom_peg_side_scale,1])cylinder(d=bottom_peg_diameter, h= bottom_peg_height -bottom_peg_chamfer);
    translate([-5,0,0])scale(v=[bottom_peg_side_scale,bottom_peg_side_scale,1])cylinder(d=bottom_peg_diameter, h= bottom_peg_height -bottom_peg_chamfer);

    translate([0,0, -bottom_peg_chamfer]){
      cylinder(d2=bottom_peg_diameter , d1 = bottom_peg_diameter -2*bottom_peg_chamfer, h= bottom_peg_chamfer);
      translate([5,0,0])scale(v=[bottom_peg_side_scale,bottom_peg_side_scale,1])cylinder(d2=bottom_peg_diameter , d1 = bottom_peg_diameter -2*bottom_peg_chamfer, h= bottom_peg_chamfer);
      translate([-5,0,0])scale(v=[bottom_peg_side_scale,bottom_peg_side_scale,1])cylinder(d2=bottom_peg_diameter , d1 = bottom_peg_diameter -2*bottom_peg_chamfer, h= bottom_peg_chamfer);
    }
  }
}

//MX series keyhole
// TODO: add alps support?
module Keyhole(tol = .1, cutThickness = 3.25, clipLength = 0)
{
  $fn = 10;
  bottom_length = 13.9+tol;
   plate_thickness = 3.51; //mm
  holeLength = bottom_length+tol*2;
  //latch nibs
  nib_radius= 1;
  nib_length = 3;

  difference(){
    translate([0,0,-cutThickness/2])cube( [holeLength, holeLength, plate_thickness+cutThickness], center =true);

    union(){
      hull(){
        translate([(holeLength)/2, ,0,-plate_thickness/2+nib_radius])rotate([90,0,0])cylinder(r =nib_radius , nib_length,center = true);
        translate([(holeLength)/2, ,-nib_length/2,-plate_thickness/2])cube([nib_radius*2, nib_length, plate_thickness]);
      }
      mirror([1,0,0])hull(){
        translate([(holeLength)/2, ,0,-plate_thickness/2+nib_radius])rotate([90,0,0])cylinder(r =nib_radius , nib_length,center = true);
        translate([(holeLength)/2, ,-nib_length/2,-plate_thickness/2])cube([nib_radius*2, nib_length, plate_thickness]);
      }
      if (clipLength != 0){
        translate([0, -sign(clipLength)*7.8-clipLength, 0])cube([20, 15.6, 40], center = true);
      }
    }
  }
}

module Stabilizer(offsets = 23.8/2)
{
  plate_thickness = 3.6; //mm
  stabilizer_width = 5;
  stabilizer_length = 12.2;
  translate([offsets,0,0])cube([stabilizer_width,stabilizer_length,plate_thickness], center = true);
  translate([-offsets,0,0])cube([stabilizer_width,stabilizer_length,plate_thickness], center = true);
}

module TrackPoint(nibLength = 20)
{
  color("red")translate([0,0,-.5])cube([4.5,4.5,5], center= true); //nib
  color("gold")cylinder(d = 2, nibLength); //nib
  color("gold")translate([0,0,nibLength])sphere(2); //nib
  translate([0,30.3/2-8,-3/2])cube([26.46, 30.3, 3], center = true);
}

module RotaryEncoder(stemLength = 13, Wheel = 0)
{
 color("grey")translate([0,0, -6.1/2])cube([11.5, 13.5, 6.1], center = true);
 cylinder(d = 7, 7.8);

 translate([0,0,7.8])difference(){
   cylinder(d = 5.8, stemLength);
   translate([-5.8/2,5.8/2-1.5,3])cube([11.5, 13.5, stemLength]);
 }
 color("grey")translate([0,0,7.8])cylinder(d = Wheel, stemLength);
}

//################ Test Calls ###################
Switch(clipLength = -7.8);
Keyhole(.1, clipLength = 3);
//Stabilizer(20);
// RotaryEncoder(Wheel = 0);
//Switch([1,1.5,1]);
//TrackPoint();

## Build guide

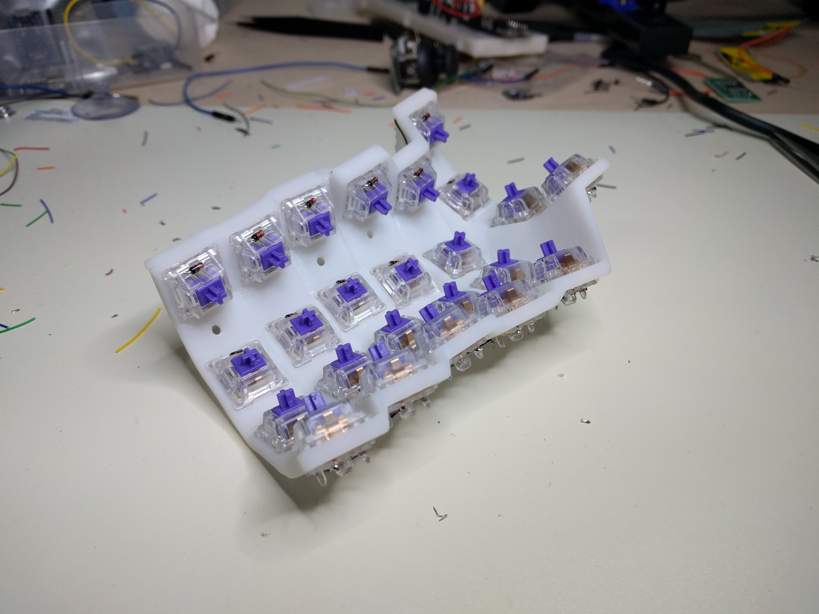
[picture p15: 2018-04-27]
Photo/Proto1Build.jpg

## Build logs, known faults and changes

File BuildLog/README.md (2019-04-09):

# Build Log
## Index
 * Printing
 * Post Processing

##Printing Process
### Post Cure
### Post process
## Actual Build
### Switches
### PCB
### Firmware
### Mounting

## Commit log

2018-05-07 Read.Me
    Read Me and Soem OpenSCAD
    [BatteryHolder.scad, Switch.scad, WARPED_Mod.scad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]
2018-06-02 more variation
    [Col1Low.stl, SwitchKalhi.scad, ThumbVer2.stl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]
2018-11-18 Quick update
    cut uneeded content. upload most recent STL and SCAD files
    [BatteryHolder.scad, Col1Low.stl, Switch.scad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]
2018-11-27 Clip Switch Moddification
    Improve code legibility
    Added Flick Switch suppor
    Added Clipped Switch suppor
    Added Rortary encoder suppor
    fixed keycaps clipping at C3R1 and C4R0
    [Switch.scad, WARPED.scad]
2018-11-28 touch up
    hotfix on innerweb
    [WARPED.scad]
2018-12-02 optimization and caps
    added keycaps to optimize clipped keys
    fixed web and inner web
    optimizing compact build.
    [Keycaps.scad, Switch.scad, WARPED.scad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]
2018-12-06 rev8 version update
    [Keycaps.scad, Switch.scad, WARPED.scad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]
2018-12-06 thumb optimization
    revert back to oleder style thumb position now that direction of optimization tas changed: remove C1R0 in order to place thumb in more realistic neutral position.
    [WARPED.scad]
2018-12-07 Waaarped test build
    commit to branch. Test print model
    [Switch.scad, WARPED.scad, WARPED.stl]
2018-12-23 Ver9 Malformed
    ver9 malformed
    keycaps and gintsugi ver 1.0
    [C1R0.scad, C1R1.scad, C2R0.scad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]
2019-01-13 Mounting Tests
    Ball Mounts Parts
    [BallMount.scad, C1R0.scad, C1R1.scad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]
2019-01-18 hyperwarped update
    ver.2
    [BallMount.scad, HyperWarp.scad, WARPED.scad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]
2019-04-09 Proto Build update
    commiting to a build
    [BallMount.scad, Gintsugiv1.0..sch, Gintsugiv1.0.kicad_pcb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]
